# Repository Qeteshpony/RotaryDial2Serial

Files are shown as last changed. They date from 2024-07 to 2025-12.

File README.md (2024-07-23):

# RotaryDial2Serial



3D Render

[Hardware Documentation](https://qeteshpony.github.io/RotaryDial2Serial)

This little board allows using the rotary dial of an old phone as an input for modern electronics by translating the signals into serial data.

You need to find the right contacts from the rotary dial mechanism and the phone hook (if you want to use it) and connect them to this board. The board will work with 3.3V or 5V and uses very little power so it can be driven directly from a Raspberry Pi or even an ESP or similar microcontroller.

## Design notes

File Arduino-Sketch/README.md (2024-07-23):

Use Arduino IDE to compile and install this sketch

You need the [ATtinyCore](https://github.com/SpenceKonde/ATTinyCore) installed and use the following settings:

- Board: "ATtiny25/45/85 (No bootloader)"
- Chip: "ATtiny 85" or "ATtiny 45" depending on what you use
- Clock Source (Only set on bootload): "8 MHz (internal)"
- millis ()/micros(): "Enabled"

Connect the board using a USBasp or other compatible ICSP programmer, then burn the bootloader and after that upload the sketch using the programmer (Sketch -> Upload Using Programmer) 

Keep in mind that the phone parts must not be connected while doing this or the upload will fail.

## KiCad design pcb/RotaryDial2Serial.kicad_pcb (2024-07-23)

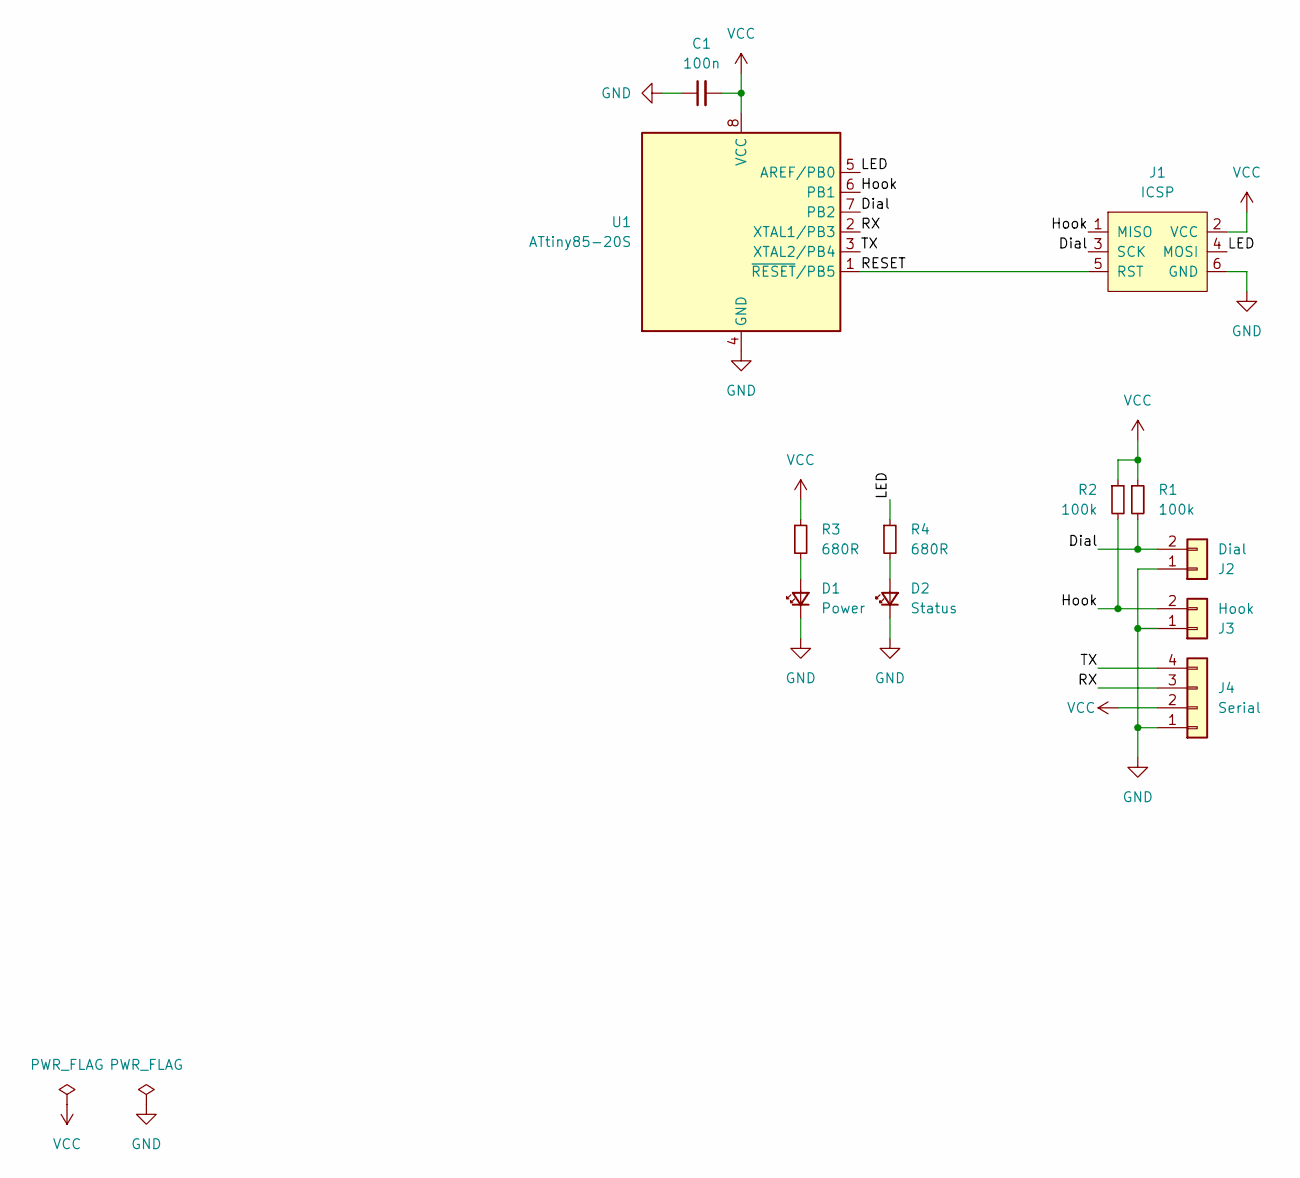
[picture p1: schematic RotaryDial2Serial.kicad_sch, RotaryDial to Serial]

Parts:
C1: 100n; C_0603_1608Metric_Pad1.08x0.95mm_HandSolder
D1: Power; LED_0603_1608Metric_Pad1.05x0.95mm_HandSolder
D2: Status; LED_0603_1608Metric_Pad1.05x0.95mm_HandSolder
J1: ICSP; PinHeader_2x03_P2.54mm_Vertical
J2: Dial; JST_PH_B2B-PH-K_1x02_P2.00mm_Vertical
J3: Hook; JST_PH_B2B-PH-K_1x02_P2.00mm_Vertical
J4: Serial; JST_PH_B4B-PH-K_1x04_P2.00mm_Vertical
R1, R2: 100k; R_0603_1608Metric_Pad0.98x0.95mm_HandSolder
R3, R4: 680R; R_0603_1608Metric_Pad0.98x0.95mm_HandSolder
U1: ATtiny85-20S; SOIC-8W_5.3x5.3mm_P1.27mm

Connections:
/Dial: J1.3 (SCK), J2.2, R1.2, U1.7 (PB2)
/Hook: J1.1 (MISO), J3.2, R2.2, U1.6 (PB1)
/LED: J1.4 (MOSI), R4.1, U1.5 (AREF/PB0)
/RESET: J1.5 (RST), U1.1 (~RESET/PB5)
/RX: J4.3, U1.2 (XTAL1/PB3)
/TX: J4.4, U1.3 (XTAL2/PB4)
GND: C1.1, D1.1 (K), D2.1 (K), J1.6 (GND), J2.1, J3.1, J4.1, U1.4 (GND)
unnamed: D1.2 (A), R3.2
unnamed: D2.2 (A), R4.2
VCC: C1.2, J1.2 (VCC), J4.2, R1.1, R2.1, R3.1, U1.8 (VCC)

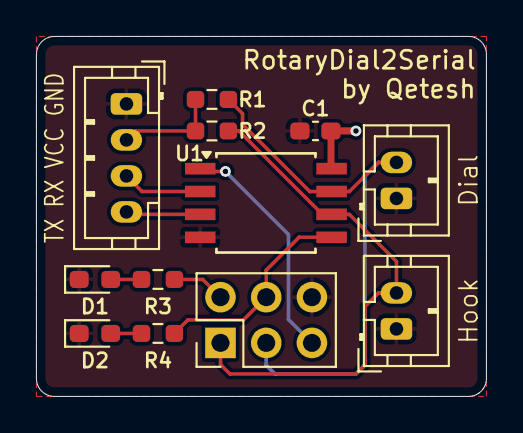
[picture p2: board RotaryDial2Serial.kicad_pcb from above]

Board: 2 copper layers, 25.0 x 20.0 mm, 12 parts (0 on the bottom side), 10 nets.

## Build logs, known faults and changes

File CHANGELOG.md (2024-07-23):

# Changelog

## 1.0.0 (2024-07-23)

### Features

* initial commit ([6768b8a](https://github.com/Qeteshpony/RotaryDial2Serial/commit/6768b8a6bfb2bd0980836f7f17ee4ed47114ae90))

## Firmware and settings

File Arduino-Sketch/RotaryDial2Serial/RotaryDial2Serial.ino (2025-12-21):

#include "SoftwareSerial.h"

// define pin numbers
#define LED   0
#define HOOK  1
#define DIAL  2
#define RX    3 
#define TX    4 

SoftwareSerial mySerial(RX, TX);

int count = 0;  // counter for the dial clicks

unsigned long lastclick;  // millis() value for last dial click
unsigned long lasthook;  // millis() value for last hook change
bool hookpos;  // current hook position
bool clicker;  // current clicker position

void setup() {
  // initialize pins
  pinMode(RX, INPUT);
  pinMode(TX, OUTPUT);
  pinMode(DIAL, INPUT);
  pinMode(HOOK, INPUT);
  pinMode(LED, OUTPUT);

  // initialize software serial
  mySerial.begin(115200);  
}

void loop() {
  // when the rotary dial sends a click, register it, count it and set the timer for debouncing
  if (digitalRead(DIAL) == 1 && clicker == 0) {
    clicker = 1;
    lastclick = millis();
    count++;
  }

  // reset the clicker after the debounce timer is up
  if (digitalRead(DIAL) == 0 && lastclick + 80 < millis()) clicker = 0;

  // when there were clicks counted and the last click was more than 200ms ago
  if (count > 0 && lastclick + 200 < millis()) {
    // check if the hook is up. If so, we take the remainder of a division by 10
    // to turn 10 into 0 and send it to the serial connection
    if (hookpos == 0) mySerial.print(count % 10);
    // reset the click counter
    count = 0;
  }

  // when the hook changed and the last change was more than 50 ms ago
  bool newhookpos = digitalRead(HOOK);
  if (lasthook + 50 < millis() && newhookpos != hookpos) {
    // store time of this hookchange for debouncing
    lasthook = millis();
    // update the hookpos
    hookpos = newhookpos;
    // send new hookpos to serial
    if (hookpos == 0) mySerial.print("u");
    else mySerial.print("d");
  }

  // switch the LED off for 25ms if a click was received, turn it only on if the hook is up
  if (lastclick + 25 > millis()) digitalWrite(LED, 0);
  else digitalWrite(LED, 1 - hookpos);
}

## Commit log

2024-07-23 feat: initial commit
    [RotaryDial2Serial.kicad_pcb, RotaryDial2Serial.kicad_sch]
2024-08-01 fix: improve debouncing for the hook switch
    [RotaryDial2Serial.ino]
2024-08-01 fix: set LED pin to output
    [RotaryDial2Serial.ino]
2024-08-01 fix: type of timer variables
    [RotaryDial2Serial.ino]
2025-12-21 fix: replace interrupt with loop checks
    The interrupt didn't work as expected because the switches in the old rotary dialers swing too much so it got replaced. This now works 100% of the time
    [RotaryDial2Serial.ino]
